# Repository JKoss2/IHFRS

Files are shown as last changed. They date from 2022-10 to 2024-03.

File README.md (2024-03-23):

# IHFRS - Integrated Home Fire Recognition System

The IHFRS is a smart-home camera that leverages the use of a FLIR Lepton 3.5 sensor to monitor a living area for abnormal spikes in temperature. It features native Apple Homekit integration and has a local web interface and WiFi host for setup.

Future work for this project includes moving processing to an ESP32, integration with Matter (to easily support multiple smart-home ecosystems), the addition of machine learning to reduce false positives, and to offer more user-controlled settings via the GUI.

**Installation**
1. On the SD card for your Raspberry Pi, **install Raspbian OS Lite**. (You must choose 32-bit if using Pi Zero W, read below)
   1. If using Raspberry Pi Imager (suggested), make sure to use the settings cog to set the following BEFORE installing...
      1. **Hostname**: your choice
      2. **Enable SSH**: (password authentication)
      3. **Set username and password**: Username must = "pi" for now. Password can be your choice.
      4. **Configure wireless LAN**: Be sure to choose a 2.4GHz capable network.
         1. **Set wireless LAN country**: "US"
      5. **Set locale settings**
   2. If you choose to flash the OS using other means, ensure you set the above settings, so you can connect wirelessly to the PI.
2. Download the IHFRS code files using either of these methods:
   1. From the "top-level" of this repository: (where you currently are)
      * Click the green "Code" button and download the zip file to your computer
      * **OR**
      * Right-click on the `IHFRS` folder, then "Download linked file as.."
3. Insert SD card into RPI and turn on. Allow RPI to boot and connect to Wi-Fi (~2 mins).
   * If you did not set up the Wi-Fi, hostname, etc., now is the time to connect a keyboard and monitor and use `sudo raspi-config` to set up those settings. There are other ways to do this as well.
4. Ensure your RPI is on your local network:
   * Use terminal or command prompt to `ping *hostname*` 
   * **OR**
   * Try connecting to RPI using SSH 
   * **OR**
   * Try connecting with FTP or SFTP utility
5. Use FTP or SFTP to upload `IHFRS` folder only to home directory `/home/pi/` on the RPI.
6. SSH into your RPI and run the following, in order:
   1. `cd /IHFRS`
   2. `sudo python init_setup.py` (~8 mins)
      * Observe the output as it runs. You will be required to answer multiple questions. No *RED* text should appear.
      * use `y` to reboot the PI when it reaches the end.
7. Make the necessary hardware connections. Pictures are shown at the very bottom of this README.
   * TCAM hardware connection (**JUMPER [MODE - GND], 5V, GND, TXD0, RXD0, SPI0_MISO, SPI0_CE0, SPI0_CLK**)
   * MQ2 Sensor connection (**5V, GND, GPIO4**) (Use "DO" (Digital Out) on the MQ2 sensor for GPIO4, **NOT** "AO")
8. In the SSH session (Working directory is still IHFRS) run `python IHFRS_run.py`
9. The code is now running. (This will be automatic later on.)

## Acknowledgements:
### Dan Julio
https://github.com/danjulio
* Hardware and base code for TCAM board featuring the FLIR Lepton 3.5 sensor.

### Todd Lawall
https://github.com/bitreaper
* Python Implementation of TCAM code and special assistance with tracking down errors.

### Ivan Kalchev
https://github.com/ikalchev
* HAP-Python Library for Homekit Integration

### Jason Burgett
https://github.com/jasbur
* RaspiWiFi - Initial WiFi configuration for RPI

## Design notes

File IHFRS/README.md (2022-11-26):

# Integrated Home Fire Recognition System
This directory contains **almost** all of the files and libraries needed to make the software run as intended. The following steps must be taken first before it can be expected to run as intended.

## TLDR
1. On the SD card for your Raspberry Pi, **install Raspbian OS Lite**. (You must choose 32-bit if using Pi Zero W, read below)
   1. If using Raspberry Pi Imager (suggested), make sure to use the settings cog to set the following BEFORE installing...
      1. **Hostname**: your choice
      2. **Enable SSH**: (password authentication)
      3. **Set username and password**: Username must = "pi" for now. Password can be your choice.
      4. **Configure wireless LAN**: Be sure to choose a 2.4GHz capable network.
         1. **Set wireless LAN country**: "US"
      5. **Set locale settings**
   2. If you choose to flash the OS using other means, ensure you set the above settings, so you can connect wirelessly to the PI.
2. Download the IHFRS code files using either of these methods:
   1. From the "top-level" of this repository: (Go back up a level)
      * Click the green "Code" button and download the zip file to your computer
      * **OR**
      * Right-click on the `IHFRS` folder, then "Download linked file as.."
3. Insert SD card into RPI and turn on. Allow RPI to boot and connect to Wi-Fi (~2 mins).
   * If you did not set up the Wi-Fi, hostname, etc., now is the time to connect a keyboard and monitor and use `sudo raspi-config` to set up those settings. There are other ways to do this as well.
4. Ensure your RPI is on your local network:
   * Use terminal or command prompt to `ping *hostname*` 
   * **OR**
   * Try connecting to RPI using SSH 
   * **OR**
   * Try connecting with FTP or SFTP utility
5. Use FTP or SFTP to upload `IHFRS` folder only to home directory `/home/pi/` on the RPI.
6. SSH into your RPI and run the following, in order:
   1. `cd /IHFRS`
   2. `sudo python init_setup.py` (~8 mins)
      * Observe the output as it runs. You will be required to answer multiple questions. No *RED* text should appear.
      * use `y` to reboot the PI when it reaches the end.
7. Make the necessary hardware connections. Pictures are shown at the very bottom of this README.
   * TCAM hardware connection (**JUMPER [MODE - GND], 5V, GND, TXD0, RXD0, SPI0_MISO, SPI0_CE0, SPI0_CLK**)
   * MQ2 Sensor connection (**5V, GND, GPIO4**) (Use "DO" (Digital Out) on the MQ2 sensor for GPIO4, **NOT** "AO")
8. In the SSH session (Working directory is still IHFRS) run `python IHFRS_run.py`
9. The code is now running. (This will be automatic later on.)

## Detailed Usage

#### tcam.py
The ```tcam.py``` file contains an object ```TCam``` used to connect to and communicate with a camera.  It manages the network socket or direct hardware connection and provides an API for sending commands to the camera and for receiving responses back from the camera.  It uses three queues to handle the asynchronous nature of the interface.  A command queue is used for outgoing commands to the camera.  Responses from the camera are pushed into two incoming queues.  Image responses are stored in a special image queue.  All other responses are stored in a response queue.  The API hides queue operation.  API operations are single threaded and do not return until a response is returned or a timeout expires.  All response packets are presented as a python dictionary built from the json response string.

#### ioctl\_numbers.py
The ```ioctl_numbers.py``` includes helpers for use when communicating with tCam-Mini via the hardware interface.  It must be included with ```tcamp.py```.

#### Hardware Interface Usage
See below for a diagram showing how to connect the tCam-Mini hardware Slave Interface to the Raspberry Pi default serial and SPI ports.

Use the Raspberry Pi Configuration tool to enable the serial interface (make sure the console on that port is disabled) and the SPI port.  Increase the maximum SPI transfer the Pi can perform by editing the ```/boot/cmdline.txt``` file and add the following string to the end of the line in that file.  Reboot the Pi after making this change.

	spidev.bufsiz=65536

Include the TCam object from ```tcam.py``` file in your program.

	from tcam import TCam

Create a reference.

	cam = TCam(is_hw=True)

Open a connection to the camera using the default serial (```/dev/serial0```) and SPI master (```/dev/spidev0.0```).

	cam.connect()

To use alternate Pi hardware, specify the device files in the connect method.

	cam.connect(spiFile='/dev/spidev0.1', serialFile='/dev/serial1')
	
#### Common API
A common API is used to access and control the attached camera.

Many API calls take an optional timeout value which specify the number of seconds to wait for a response when using the socket interface.  By default the timeout value is 10 seconds.

#### start\_stream(self, delay\_msec=0, num\_frames=0, timeout=None)

	rsp = cam.start_stream()

Sends a ```stream_on``` command to the attached camera.

| Argument | Description |
| --- | --- |
| delay_msec | Delay, in mSec, between frames.  A value of 0 specifies fastest stream.  Non-zero values should be greater than 250 mSec. |
| num_frames | Number of frames to send.  A value of 0 specifies to stream until stopped. |

Returns the ```cam_info``` json response to the command, typically 

	{"cam_info":{"info_value":1,"info_string":"stream_on success"}}

#### stop\_stream(self, timeout=None)

	rsp = cam.stop_stream()

Sends a ```stream_off``` command to the attached camera.

Returns the ```cam_info``` json response to the command.

#### get\_image(self, timeout=None)

	img = cam.get_image()

Sends a ```get_image``` command to the attached camera.

Returns the ```image``` json response.  See the demo code for examples how to process the response into an image using the radiometric and telemetry data.

#### get\_frame(self)

	img = cam.get_frame()

Used to get images from the internal queue when streaming.

Returns an ```image``` json response or None if there are no images available.

#### frame\_count(self)

	num = cam.frame_count()

Returns the number of pending images in the internal queue.  Useful while streaming to determine if there are images to process.

#### run\_ffc(self, timeout=None)
	
	rsp = cam.run_ffc()

Sends a ```run_ffc``` command to the attached camera to initiate a Flat Field Correction.

Returns the ```cam_info``` json response to the command.

#### get\_status(self, timeout=None)

	rsp = cam.get_status()

Sends a ```get_status``` command to the attached camera.

Returns the ```status``` json response.  For example

	{"status":{"Camera":"tCam-Mini-87E9","Model":262402,"Version":"3.0","Time":"9:55:48.149","Date":"8/7/22"}}

#### set\_time(self, hour=None, minute=None, second=None, dow=None, day=None, month=None, year=None, timeout=None)

	rsp = cam.set_time(9, 45, 00, 1, 7, 8, 52)

Sends a ```set_time``` command to the attached camera.  The above example sets the time 09:45:00 on Sunday Aug 7, 2022.

| Argument | Description |
| --- | --- |
| hour | Hour 0 - 23 |
| minute | Minute 0 - 59 |
| second | Second 0 - 59 |
| dow | Day of Week starting with Sunday 1-7 |
| day | Day of Month 1-28 to 1-31 depending |
| month | Month 1-12 |
| year | Year offset from 1970 |

All arguments are required.

Returns the ```cam_info``` json response to the command.

#### get\_config(self, timeout=None)

	rsp = cam.get_config()

Sends a ```get_config``` command to the attached camera.

Returns the ```config``` json response.  For example

	{"config":{"agc_enabled":0,"emissivity":98,"gain_mode":2}}

#### set\_config(self, agc\_enabled=1, emissivity=98, gain\_mode=2, timeout=None)

	rsp = cam.set_config(0, 96, 0)

Sends a ```set_config``` command to the attached camera.  The above example sets AGC off, the emissivity to 96% and gain mode too High.

| Argument | Description |
| --- | --- |
| agc_enabled | Lepton AGC Mode: 1: Enabled, 0: Disabled (Radiometric output) |
| emissivity | Lepton Emissivity: 1 - 100 (integer percent) |
| gain_mode | Lepton Gain Mode: 0: High, 1: Low, 2: Auto |

All arguments are required.

Returns the ```cam_info``` json response to the command.

#### set\_config\_agc(self, agc\_enabled=1, timeout=None)

	rsp = cam.set_config_agc(0)

Sends a ```set_config``` command to the attached camera with only the agc_enabled argument.  The above example sets AGC off.

| Argument | Description |
| --- | --- |
| agc_enabled | Lepton AGC Mode: 1: Enabled, 0: Disabled (Radiometric output) |

Returns the ```cam_info``` json response to the command.

#### set\_config\_emissivity(self, emissivity=98, timeout=None)

	rsp = cam.set_config_emissivity(96)

Sends a ```set_config``` command to the attached camera with only the emissivity argument.  The above example sets the emissivity to 96%.

| Argument | Description |
| --- | --- |
| emissivity | Lepton Emissivity: 1 - 100 (integer percent) |

Returns the ```cam_info``` json response to the command.

#### set\_config\_gain\_mode(self, gain\_mode=2, timeout=None)

	rsp = cam.set_config(0)

Sends a ```set_config``` command to the attached camera with only the gain_mode argument.  The above example sets the gain mode too High.

| Argument | Description |
| --- | --- |
| gain_mode | Lepton Gain Mode: 0: High, 1: Low, 2: Auto |

Returns the ```cam_info``` json response to the command.

#### get\_lep\_cci(self, command=0x4ECC, length=4, timeout=None)

	cci_data = cam.get_lep_cci(0x4EBC, 8)

Sends a ```get_lep_cci``` command to the attached camera.  The above example gets the RAD Flux Linear Parameters.  The command default arguments get the RAD Spotmeter Region of Interest (ROI).

| Argument | Description |
| --- | --- |
| command | 16-bit Lepton COMMAND register value.  Issuing RAD commands requires setting the OEM Bit (Bit 14, value = 0x4000) in the command word in addition to setting the rest of the command word bits. |
| length | Number of 16-bit words to read (1-512) |

All arguments are required.

Returns the ```cci_reg``` json response to the command.  The example will return

	{"command":20156,"length":8,"status":63750,"data":"BQAAADA3MjYtMDEAAAAAAA=="}}

Refer to the Flir document "Software Interface Description Document (IDD)" Document Number: 110-0144-04 Rev 200 for a complete description of the CCI interface including commands, command lengths and data format.

#### set\_lep\_cci(self, command, data, timeout=None)

	reg_array = array.array('H', [20, 20, 21, 21])
	enc_data = reg_array.tobytes()
	rsp = cam.set_lep_cci(0x4ECD, enc_data)

Sends a ```set_lep_cci``` command to the attached camera.  The above example sets the spot meter region of interest to (20, 20) - (21, 21).

| Argument | Description |
| --- | --- |
| command | 16-bit Lepton COMMAND register value.  Issuing RAD commands requires setting the OEM Bit (Bit 14, value = 0x4000) in the command word in addition to setting the rest of the command word bits. |
| data | Data to write to the camera.  Must be a multiple of 16-bit words. |

All arguments are required.

Returns the ```cci_reg``` json response to the command.  The example will return

	{"cci_reg":{"command":20173,"length":0,"status":6}}

Take care using this command. It is possible to crash the Lepton or tCam camera (a power-cycle should restore normal operation).

#### set\_spotmeter(self, c1=79, c2=80, r1=59, r2=60, timeout=None)

	rsp = cam.set_spotmeter(90, 92, 70, 72)

Sends a ```set_spotmeter``` command to the attached camera.  The above example sets the spot meter region of interest to (90, 70) - (92, 72).

| Argument | Description |
| --- | --- |
| c1 | Spotmeter column 1: Left X-axis spotmeter box coordinate (0-159) |
| c2 | Spotmeter column 2: Right X-axis spotmeter box coordinate (0-159) |
| r1 | Spotmeter row 1: Top Y-axis spotmeter box coordinate (0-119) |
| r2 | Spotmeter row 2: Bottom Y-axis spotmeter box coordinate (0-119) |

All arguments are required.

Returns the ```cam_info``` json response to the command.

#### get\_wifi(self, timeout=None)

	rsp = cam.get_wifi()

Sends a ```get_wifi``` command to the attached camera.

Returns the ```wifi``` response.  For example

	{"wifi":{"ap_ssid":"tCam-Mini-289B","sta_ssid":"","flags":15,"ap_ip_addr":"192.168.4.1","sta_ip_addr":"192.168.4.2","sta_netmask":"255.255.255.0","cur_ip_addr":"10.0.1.123"}}

#### set\_wifi\_ap(self, ap\_ssid, ap\_pw, timeout=None)

	cam.set_wifi_ap("AP_SSID", "AP_PASSWORD")

Sends a ```set_wifi``` command to the attached camera to configure it as an Access Point with the specified SSID and password.

| Argument | Description |
| --- | --- |
| ap_ssid | Access Point SSID (1-32 characters).  Also becomes the camera name. |
| ap_pw | Access Point WPA password (8-32 characters). |

All arguments are required.

There is no return value.  You must call ```cam.disconnect()``` following this call since the camera will have disconnected the socket.

#### set\_wifi\_sta(self, sta\_ssid, sta\_pw, is\_static=False, sta\_ip\_addr="192.168.0.2", sta\_ip\_netmask="255.255.255.0", timeout=None)

	cam.set_wifi_sta("STA_SSID", "STA_PW")

Sends a ```set_wifi``` command to the attached camera to configure it as a client to an existing WiFi network obtaining a DHCP-served IP address.

	cam.set_wifi_sta("TA_SSID", "STA_PW", True, "10.0.1.73", "255.255.255.0")

Sends a ```set_wifi``` command to the attached camera to configure it as a client to an existing WiFi network with the specified static IP address.

| Argument | Description |
| --- | --- |
| sta_ssid | Existing WiFi network SSID (1-32 characters) |
| sta_pw | Existing WiFi network password (8-32 characters) |
| is_static | Set True to configure a static IP address, False for a DHCP-served address |
| sta_ip_addr | Static IP address string |
| sta_ip_netmask | Static IP address netmask string |

Only ```sta_ssid``` and ```sta_pw``` are required. 

There is no return value.  You must call ```cam.disconnect()``` following this call since the camera will have disconnected the socket.

#### set\_static\_ip(self, is\_static=False, sta\_ip\_addr="192.168.0.2", sta\_ip\_netmask="255.255.255.0", timeout=None)

	cam.set_static_ip()
	
Sends a ```set_wifi``` command to the attached camera to configure it to receive a DHCP-served IP address.

	cam.set_static_ip(True, "10.0.1.73", "255.255.255.0")
	
Sends a ```set_wifi``` command to the attached camera to configure it with a static IP address (10.0.1.73 in this example).

| Argument | Description |
| --- | --- |
| is_static | Set True to configure a static IP address, False for a DHCP-served address |
| sta_ip_addr | Static IP address string |
| sta_ip_netmask | Static IP address netmask string |

This command should only be run for a WiFi connected camera in STA mode or for an ethernet connected tCam-POE.  It will have no effect for a WiFi connected camera acting as an Access Point.

There is no return value.  You must call ```cam.disconnect()``` following this call since the camera will have disconnected the socket.

#### disconnect(self)

	cam.disconnect()
	
Disconnect the driver from the camera.

#### shutdown(self)

	cam.shutdown()
	
Shut down the driver before finishing your program to close the socket or hardware connection and terminate an internal manager thread.

### Demos
The ```examples``` directory contains several example python programs using the TCam driver.

The example programs take command line arguments.  Look at the source code for example-specific arguments but all socket examples allow specifying the camera IP address as shown.  By default the TCam driver attempts to connect to the default tCam-as-AP address of ```192.168.4.1```.

	disp_image.py -i 10.0.1.71

Some of the demo programs like ```disp_file.py``` and ```dump_image.py``` must be run in the same directory as the ```palettes``` directory.

The ```streamtest_hw.py``` program demonstrates how to use the driver with the hardware interface on a Raspberry Pi.  A tCam-Mini must be connected as shown below.

### tCam-Mini Hardware Interface Connections

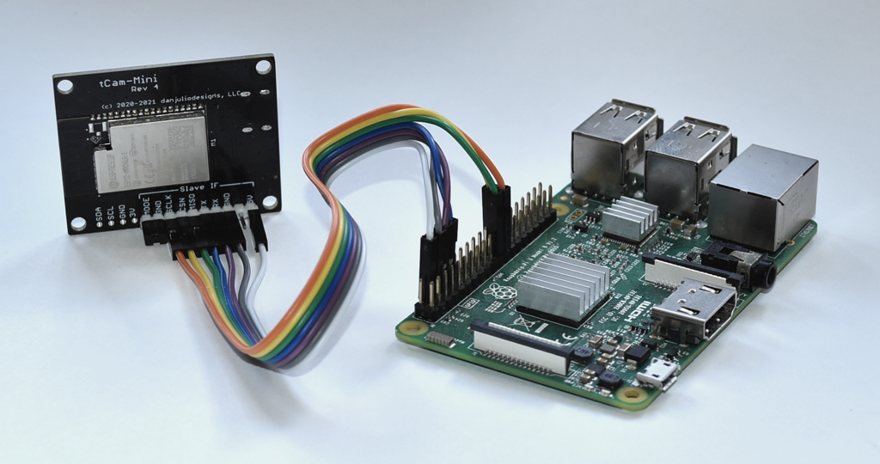
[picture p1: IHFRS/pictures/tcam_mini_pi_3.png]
tCam-Mini with Pi 3


The tCam-Mini hardware Slave Interface is enabled on power-up when the tCam-Mini detects a jumper from the MODE pin to GND.  Seven wires interface the Slave Interface to the Pi and provide power as shown below.  Be sure to make all the connections before applying power to the Pi.

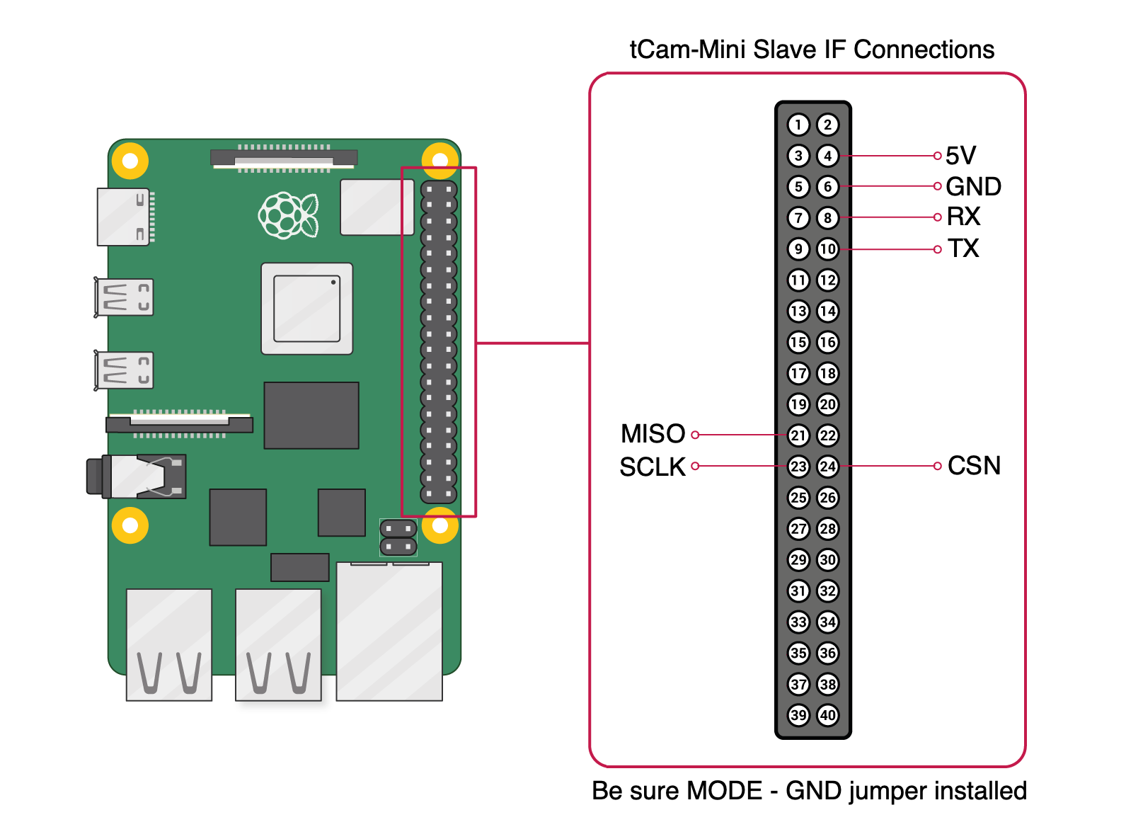
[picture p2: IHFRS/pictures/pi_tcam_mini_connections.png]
tCam-Mini Wiring Diagram


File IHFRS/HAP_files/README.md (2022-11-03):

     
# HAP-python

HomeKit Accessory Protocol implementation in python 3.
With this project, you can integrate your own smart devices and add them to your
iOS Home app. Since Siri is integrated with the Home app, you can start voice-control your
accessories right away.

Main features:

* Camera - HAP-python supports the camera accessory from version 2.3.0!
* asyncio support - You can run various tasks or accessories in the event loop.
* Out of the box support for Apple-defined services - see them in [the resources folder](PycharmProjects/IHFRS Project/Senior-Design/IHFRS/HAP_files/pyhap/resources).
* Secure pairing by just scanning the QR code.
* Integrated with the home automation framework [Home Assistant](https://github.com/home-assistant/home-assistant).

The project was developed for a Raspberry Pi, but it should work on other platforms. To kick-start things,
you can open `main.py` or `busy_home.py`, where you will find some fake accessories.
Just run one of them, for example `python3 busy_home.py`, and you can add it in
the Home app (be sure to be in the same network).
Stop it by hitting Ctrl+C.

There are example accessories as well as integrations with real products
in [the accessories folder](PycharmProjects/IHFRS Project/Senior-Design/IHFRS/HAP_files/accessories). See how to configure your camera in
[camera_main.py](PycharmProjects/IHFRS Project/Senior-Design/IHFRS/HAP_files/camera_main.py).

## Table of Contents
1. [API](#API)
2. [Installation](#Installation)
3. [Setting up a camera](#Camera)
4. [Run at boot (and a Switch to shutdown your device)](#AtBoot)
5. [Notice](#Notice)

## Installation 

As of version 3.5.1, HAP-python no longer supports python older than 3.6, because we
are moving to asyncio. If your platform does not have a compatible python out of the
box, you can install it manually or just use an older version of HAP-python.

As a prerequisite, you will need Avahi/Bonjour installed (due to zeroconf package).
On a Raspberry Pi, you can get it with:
```
$ sudo apt-get install libavahi-compat-libdnssd-dev
```
`avahi-utils` may also fit the bill. Then, you can install with `pip3` (you will need `sudo` or `--user` for the install):
```sh
$ pip3 install HAP-python[QRCode]
```

This will install HAP-python in your python packages, so that you can import it as `pyhap`. To uninstall, just do:
```
$ pip3 uninstall HAP-python
```

## API 

A typical flow for using HAP-python starts with implementing an Accessory. This is done by
subclassing [Accessory](PycharmProjects/IHFRS Project/Senior-Design/IHFRS/HAP_files/pyhap/accessory.py) and putting in place a few details
(see below). After that, you give your accessory to an AccessoryDriver to manage. This
will take care of advertising it on the local network, setting a HAP server and
running the Accessory. Take a look at [main.py](PycharmProjects/IHFRS Project/Senior-Design/IHFRS/HAP_files/main.py) for a quick start on that.

```python
from pyhap.accessory import Accessory, Category
import pyhap.loader as loader

class TemperatureSensor(Accessory):
    """Implementation of a mock temperature sensor accessory."""

    category = Category.SENSOR  # This is for the icon in the iOS Home app.

    def __init__(self, *args, **kwargs):
        """Here, we just store a reference to the current temperature characteristic and
        add a method that will be executed every time its value changes.
        """
        # If overriding this method, be sure to call the super's implementation first.
        super().__init__(*args, **kwargs)

        # Add the services that this Accessory will support with add_preload_service here
        temp_service = self.add_preload_service('TemperatureSensor')
        self.temp_char = temp_service.get_characteristic('CurrentTemperature')

        # Having a callback is optional, but you can use it to add functionality.
        self.temp_char.setter_callback = self.temperature_changed

    def temperature_changed(self, value):
        """This will be called every time the value of the CurrentTemperature
        is changed. Use setter_callbacks to react to user actions, e.g. setting the
        lights On could fire some GPIO code to turn on a LED (see pyhap/accessories/LightBulb.py).
        """
        print('Temperature changed to: ', value)

    @Acessory.run_at_interval(3)  # Run this method every 3 seconds
    # The `run` method can be `async` as well
    def run(self):
        """We override this method to implement what the accessory will do when it is
        started.

        We set the current temperature to a random number. The decorator runs this method
        every 3 seconds.
        """
        self.temp_char.set_value(random.randint(18, 26))

    # The `stop` method can be `async` as well
    def stop(self):
        """We override this method to clean up any resources or perform final actions, as
        this is called by the AccessoryDriver when the Accessory is being stopped.
        """
        print('Stopping accessory.')
```

## Service Callbacks

When you are working with tightly coupled characteristics such as "On" and "Brightness,"
you may need to use a service callback to receive all changes in a single request.

With characteristic callbacks, you do now know that a "Brightness" characteristic is
about to be processed right after an "On" and may end up setting a LightBulb to 100%
and then dim it back down to the expected level.

```python
from pyhap.accessory import Accessory
from pyhap.const import Category
import pyhap.loader as loader

class Light(Accessory):
    """Implementation of a mock light accessory."""

    category = Category.CATEGORY_LIGHTBULB  # This is for the icon in the iOS Home app.

    def __init__(self, *args, **kwargs):
        """Here, we just store a reference to the on and brightness characteristics and
        add a method that will be executed every time their value changes.
        """
        # If overriding this method, be sure to call the super's implementation first.
        super().__init__(*args, **kwargs)

        # Add the services that this Accessory will support with add_preload_service here
        serv_light = self.add_preload_service('Lightbulb')
        self.char_on = serv_light.configure_char('On', value=self._state)
        self.char_brightness = serv_light.configure_char('Brightness', value=100)

        serv_light.setter_callback = self._set_chars

    def _set_chars(self, char_values):
        """This will be called every time the value of the on of the
        characteristics on the service changes.
        """
        if "On" in char_values:
            print('On changed to: ', char_values["On"])
        if "Brightness" in char_values:
            print('Brightness changed to: ', char_values["Brightness"])

    @Acessory.run_at_interval(3)  # Run this method every 3 seconds
    # The `run` method can be `async` as well
    def run(self):
        """We override this method to implement what the accessory will do when it is
        started.

        We set the current temperature to a random number. The decorator runs this method
        every 3 seconds.
        """
        self.char_on.set_value(random.randint(0, 1))
        self.char_brightness.set_value(random.randint(1, 100))

    # The `stop` method can be `async` as well
    def stop(self):
        """We override this method to clean up any resources or perform final actions, as
        this is called by the AccessoryDriver when the Accessory is being stopped.
        """
        print('Stopping accessory.')
```

## Setting up a camera 

The [Camera accessory](PycharmProjects/IHFRS Project/Senior-Design/IHFRS/HAP_files/pyhap/camera.py) implements the HomeKit Protocol for negotiating stream settings,
such as the picture width and height, number of audio channels and others.
Starting a video and/or audio stream is very platform specific. Because of this,
you need to figure out what video and audio settings your camera supports and set them
in the `options` parameter that is passed to the `Camera` Accessory. Refer to the
documentation for the `Camera` contructor for the settings you need to specify.

By default, HAP-python will execute the `ffmpeg` command with the negotiated parameters
when the stream should be started and will `terminate` the started process when the
stream should be stopped (see the default: `Camera.FFMPEG_CMD`).
If the default command is not supported or correctly formatted for your platform,
the streaming can fail.

For these cases, HAP-python has hooks so that you can insert your own command or implement
the logic for starting or stopping the stream. There are two options:

1. Pass your own command that will be executed when the stream should be started.

    You pass the command as a value to the key `start_stream_cmd` in the `options` parameter to
    the constuctor of the `Camera` Accessory. The command is formatted using the
    negotiated stream configuration parameters. For example, if the negotiated width
    is 640 and you pass `foo start -width {width}`, the command will be formatted as
    `foo start -width 640`.

    The full list of negotiated stream configuration parameters can be found in the
    documentation for the `Camera.start` method.

2. Implement your own logic to start, stop and reconfigure the stream.

    If you need more flexibility in managing streams, you can directly implement the
    `Camera` methods `start`, `stop` and `reconfigure`. Each will be called when the
    stream should be respectively started, stopped or reconfigured. The start and
    reconfigure methods are given the negotiated stream configuration parameters.

    Have a look at the documentation of these methods for more information.

Finally, if you can take snapshots from the camera, you may want to implement the
`Camera.snapshot` method. By default, this serves a stock photo.

## Run at boot 
This is a quick way to get `HAP-python` to run at boot on a Raspberry Pi. It is recommended
to turn on "Wait for network" in `raspi-config`. If this turns to be unreliable, see
[this](https://www.raspberrypi.org/forums/viewtopic.php?f=66&t=187225).

Copy the below in `/etc/systemd/system/HAP-python.service` (needs sudo).
```
[Unit]
Description = HAP-python daemon
Wants = pigpiod.service  # Remove this if you don't depend on pigpiod
After = local-fs.target network-online.target pigpiod.service

[Service]
User = lesserdaemon  # It's a good idea to use some unprivileged system user
# Script starting HAP-python, e.g. main.py
# Be careful to set any paths you use, e.g. for persisting the state.
ExecStart = /usr/bin/python3 /home/lesserdaemon/.hap-python/hap-python.py

[Install]
WantedBy = multi-user.target
```

Test that everything is fine by doing:

```sh
> sudo systemctl start HAP-python
> systemctl status HAP-python
> sudo journalctl -u HAP-python  # to see the output of the start up script.
> sudo systemctl stop HAP-python
```

To enable or disable at boot, do:

```sh
> sudo systemctl enable HAP-python
> sudo systemctl disable HAP-python
```

### Shutdown switch

If you are running `HAP-python` on a Raspberry Pi, you may want to add a
[Shutdown Switch](pyhap/accessories/ShutdownSwitch.py) to your Home. This is a
Switch Accessory, which, when triggered, executes `sudo shutdown -h now`, i.e.
it shutdowns and halts the Pi. This allows you to safely unplug it.

For the above to work, you need to enable passwordless `/sbin/shutdown` to whichever
user is running `HAP-python`. For example, do:
```sh
$ sudo visudo # and add the line: "<hap-user> ALL=NOPASSWD: /sbin/shutdown".
```

## Notice 

Some HAP know-how was taken from [HAP-NodeJS by KhaosT](https://github.com/KhaosT/HAP-NodeJS).

I am not aware of any bugs, but I am more than confident that such exist. If you find any,
please report and I will try to fix them.

Suggestions are always welcome.

Have fun!

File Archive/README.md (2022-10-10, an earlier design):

# Senior-Design
Hey guys, I just uploaded disp_spot.py file that I've been modifying. 
when changes made replace this file in your python examples folder, for me it looks like this /home/pi/Desktop/Lepton/lepton-master/ESP32/python/examples

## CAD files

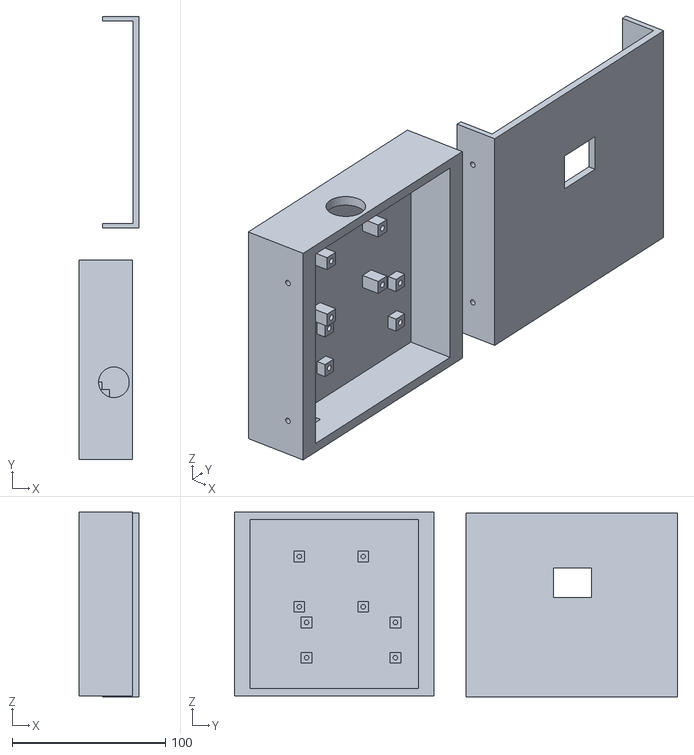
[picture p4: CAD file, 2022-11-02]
3D Printer Files/IHFRS Casing V1.stl
39.3 x 289.0 x 120.6

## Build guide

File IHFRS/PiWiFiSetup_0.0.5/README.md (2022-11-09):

# PiWiFiSetup

PiWiFiSetup is a program to headlessly configure a Raspberry Pi's WiFi
connection using any other WiFi-enabled device (much like the way
a Chromecast or similar device can be configured).

It was tested on Raspberry Pi 3B+ with debian buster

It is based on the wonderful work of Jason Burgett <https://github.com/jasbur/RaspiWiFi>

However there are some key differences:

- It is intended to work as a standalone app launching any dependencies like
 hostpad and dnsmasq as sub-processes and stopping them on finish.

- It doesn't restart the device, just setups the WiFi and exits.

- It doesn't regenerate wpa_supplicant.conf on every run but instead just edit
 the first instance of a network={} block and leave every other setting intact.

- There is no installation script and the decision on when to run the app depends
 entirely on the user/integrator

- When you connect to the AP it would act as a captive portal and take you to the
 configuration page without the need to open a specific address

## PACKAGING

To build a .deb package that you can install directly you can run:

``` bash
dpkg-buildpackage -us -uc -b
```

The package would then be in the parent directory

## INSTALLATION

If you have build a package all you need to do is install it:

``` bash
apt install ./pi-wifi-setup_*_all.deb
```

Or you can install only the required packages.
On debian buster to satisfy the dependencies you need to run:

``` bash
apt install python3-flask dnsmasq-base hostapd
```

In the package are included .service and .timer systemd control files.
The service would only start if there isn't any connection in state UP.
The timer would run only once after boot.
You can override those defaults using:

``` bash
systemctl edit pi-wifi-setup.service
systemctl edit pi-wifi-setup.timer
```

## CONFIGURATION

The configuration file the app uses is /etc/PiWiFiSetup/PiWiFiSetup.conf.
The file can be missing in which case the defaults are as follows:

``` config
ssid_prefix="Pi $id Wifi Setup"
wpa_enabled=1
wpa_key="1234567890"
```

The $id is replaced with the serial-number of the device
In case you save the file via the web interface it would be update or created if missing.

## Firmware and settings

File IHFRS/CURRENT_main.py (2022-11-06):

#!/usr/bin/env python3

# Main Imports TODO: Move imports to __init.py?
import logging
import os
import signal
import sys
import time

# Multi-Processing Related Imports
from multiprocessing import Event, Process, Queue

# TCAM Related Imports
import argparse
import array
import base64
from tcam import TCam

# HomeKit Integration Related Imports
from pyhap.accessory import Accessory, Bridge
from pyhap.accessory_driver import AccessoryDriver
from pyhap.const import CATEGORY_SENSOR

# Smoke Sensor Related Imports
import RPi.GPIO as GPIO

# Other Imports
from email.mime.text import MIMEText
from email.mime.multipart import MIMEMultipart
import ssl
import smtplib
# from twilio.rest import Client
# import notification

# Setup for Smoke Sensor
SMOKEPIN = 4
GPIO.setmode(GPIO.BCM)
GPIO.setup(SMOKEPIN, GPIO.IN)

# Declare and initialize global variables FIXME: Pass updated parameters/values between processes. Use Queue for this
temp = 0
smokeStatus = 0


# Logger Setup
def init_logger():
    logger_format = "%(asctime)s %(levelname)-8.8s [%(funcName)24s():%(lineno)-3s] %(message)s"
    formatter = logging.Formatter(logger_format)

    logger = logging.getLogger()
    logger.setLevel(logging.DEBUG)
    handler = logging.StreamHandler()
    handler.setFormatter(formatter)
    logger.addHandler(handler)
    return logger


logger = init_logger()

# Main SIGINT / SIGTERM Handlers
main_stop_event = Event()

# TODO: Add SIGTERM / SIGINT Handlers
def main_sigint_handler(signum, frame):
    logger.debug('')
    main_stop_event.set()


def main_sigterm_handler(signum, frame):
    logger.debug('')
    main_stop_event.set()


# Children SIGINT / SIGTERM Handlers (let Main process handle this)
def children_sigint_handler(signum, frame):
    logger.debug('')


def children_sigterm_handler(signum, frame):
    logger.debug('')


def stop_procs(self):  # TODO: Add graceful shutdowns

    self.shutdown_event.set()

    end_time = time.time() + self.STOP_WAIT_SECS
    num_terminated = 0
    num_failed = 0

    # -- Wait up to STOP_WAIT_SECS for all processes to complete
    for proc in self.procs:
        join_secs = max(0.0, min(end_time - time.time(), STOP_WAIT_SECS))
        proc.proc.join(join_secs)

    # -- Clear the procs list and _terminate_ any procs that
    # have not yet exited
    while self.procs:
        proc = self.procs.pop()
        if proc.proc.is_alive():
            proc.terminate()
            num_terminated += 1
        else:
            exitcode = proc.proc.exitcode
            if exitcode:
                num_failed += 1

    return num_failed, num_terminated


class IHFRSSensor(Accessory):  # TODO: Move to module

    category = CATEGORY_SENSOR

    def __init__(self, *args, **kwargs):
        super().__init__(*args, **kwargs)
        # Add the services that this Accessory will support with add_preload_service here
        temp_service = self.add_preload_service('TemperatureSensor')
        smoke_service = self.add_preload_service('SmokeSensor')

        self.temp_char = temp_service.get_characteristic('CurrentTemperature')
        self.smoke_char = smoke_service.get_characteristic('SmokeDetected')

    @Accessory.run_at_interval(5)
    async def run(self):
        self.temp_char.set_value(temp)
        self.smoke_char.set_value(smokeStatus)


def get_accessory(driver):
    return IHFRSSensor(driver, 'IHFRS')


def homekit_process():  # TODO: Move to module
    driver = AccessoryDriver(port=34985)
    driver.add_accessory(accessory=get_accessory(driver))
    signal.signal(signal.SIGTERM, driver.signal_handler)
    driver.start()


def smoke_process():  # TODO: Move to module
    while not shutdown_event.is_set():
        try:
            if GPIO.input(SMOKEPIN):
                smokeStatus = 0
                print("Checking for Gas/Smoke")
            elif GPIO.input(not SMOKEPIN):
                smokeStatus = 1
                print("SMOKE DETECTED!!!!")
                print("SMOKE DETECTED!!!!")
                print("SMOKE DETECTED!!!!")
                #           Debounce for Smoke Detection
                time.sleep(3)
        except queue.Empty:
            continue
        time.sleep(3)


def tcam_process():  # TODO: Move to module
    #
    # Connect to tCam
    #
    cam = TCam(is_hw=True)
    stat = cam.connect()
    if stat["status"] != "connected":
        print(f"Could not connect to Tcam")
        #         notification.notification(f"Camera disconnected, check connection!", f"Camera disconnected")
        cam.shutdown()

        # sys.exit()

    #
    # OEM Mask
    #
    COMMAND_OEM_MASK = 0x4000

    #
    # Request the RAD T-Linear resolution (RAD 0x0EC4)
    #    Response is 0 for 0.1 C (Low Gain), 1 for 0.01 C (High Gain)
    #
    rsp = cam.get_lep_cci(COMMAND_OEM_MASK | 0x0EC4, 2)
    cam.set_spotmeter(0, 159, 0, 119)
    #
    # Convert the json response into an array of 2 16-bit words
    #  Index  : Value
    #    0    : Response[15:0]
    #    1    : Response[31:16]
    #
    while True:
        stat = cam.connect()
        if stat["status"] != "connected":
            print(f"Could not connect to Tcam")
            # notification.notification(f"Camera disconnected, check connection!", f"Camera disconnected")
            cam.shutdown()
        rsp_vals = rsp["cci_reg"]
        dec_data = base64.b64decode(rsp_vals["data"])
        reg_array = array.array('H', dec_data)
        if reg_array[0] == 0:
            res = 0.1
        else:
            res = 0.01

        print(f"T-Linear resolution = {res}")

        #
        # Request the RAD Spotmeter Value (RAD 0xED0)
        #
        rsp = cam.get_lep_cci(COMMAND_OEM_MASK | 0x0ED0, 4)

        #
        # Convert the json response into an array of 4 16-bit words
        #  Index  : Value
        #    0    : Spotmeter Value
        #    1    : Spotmeter Max Value
        #    2    : Spotmeter Min Value
        #    3    : Spotmeter Population
        #
        rsp_vals = rsp["cci_reg"]
        dec_data = base64.b64decode(rsp_vals["data"])
        reg_array = array.array('H', dec_data)

        #
        # Convert the Spotmeter Value into degrees C
        #   Temp = (Spotmeter Value / (1 / T-Linear Resolution)) - 273.15

        temp = (reg_array[0] / (1 / res)) - 273.15
        tempMax = (reg_array[1] / (1 / res)) - 273.15
        tempMin = (reg_array[2] / (1 / res)) - 273.15

        if tempMax > 40:
            print(f"HOT DETECTED!!!")
            print(f"Temperature Max= {tempMax} C")
            print(f"Temperature Min= {tempMin} C")
            print(f"Temperature spot= {temp} C")
            # notification.notification(f"Hot spot detected, please check the area!!! Max temperature = {tempMax} C", f"Fire")

        else:
            print(f"Temperature Max= {tempMax} C")
            print(f"spot average = {temp} C")
            print(f"Temperature Min= {tempMin} C")

        time.sleep(3)


if __name__ == "__main__":
    try:
        # Define Processes
        smokeProcess = Process(target=smoke_process)
        tcamProcess = Process(target=tcam_process)
        hkProcess = Process(target=homekit_process)

        # Start Processes
        smokeProcess.start()
        tcamProcess.start()
        hkProcess.start()

    except KeyboardInterrupt:
        smokeProcess.terminate()
        tcamProcess.terminate()
        hkProcess.terminate()
        print("Interrupted.")

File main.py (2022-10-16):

import camera_hw
import notification
import gas_sensor
import RPi. GPIO as GPIO
import time
from tcam import TCam

GPIO.setmode(GPIO.BCM)
GPIO.setup(4, GPIO.IN)
cam= TCam(is_hw=True)
cam.connect()
def main():
    while True:
        if (gas_sensor.Gas(GPIO)):
            notification.notification(f"Gas leak", f"Gas leak")
        #tempMax=cam.camera(cam2)
        tempMax=camera_hw.get_data(cam)
        if tempMax !=False:  #(camera_hw.get_data(cam))
            notification.notification(f"Hot Surface, check the area!!!"+str(tempMax)+"C",f"Fire") #
        
        
        time.sleep(1)
        
            
        
main()        

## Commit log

2022-10-27 Add 3D print folder
2022-10-27 Finished adding basic code for HomeKit Integration and Multi-Threading support
2022-11-06 Add initial configuration files and some TODOs
    [boot_config_init.txt, cmdline_config_init.txt]
2022-11-24 Reconfigured initial installation..
    [cmdline_config_init.txt]
